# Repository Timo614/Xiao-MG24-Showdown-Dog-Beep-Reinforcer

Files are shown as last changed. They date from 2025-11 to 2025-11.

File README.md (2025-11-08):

This project demonstrates a Xiao MG24 and a custom Xiao footprint board used for sending reinforcement beeps to dog collars that operate on the 433 MHz frequency. My dogs are heavy barkers and, given their nature as rescue dogs, are jittery when it comes to people walking by outside. We ended up getting these collars off Amazon as we had issues where they would run in the backyard and excessively bark at neighbors. I opted to only store the beep element as we don't use the other features of the collars and a single beep is enough to get them to stop in most cases.

## Program Capabilities

The project in its final form has the Xiao MG24 board connected via headers to my Explorer 433 expansion board. The expansion board has a light sensor, AHT21, RFM69HCW, and two HY2.0 "Grove" inputs (one for i2c and another for uart). 

I've provided two ino files for Arduino:
- src/Explorer433-Matter.ino - a project which utilizes the Matter over Thread functionality of the Xiao MG24 to send temperature information from the AHT21 and allow triggering of dogs via Matter
- src/Explorer433.ino - a project utilizing an I2C based Grove OLED Display and a Grove button connected to the RX pin of the Xiao MG24 to demonstrate functionality in an off grid manner

The Xiao MG24 is connected to the RFM69HCW via the Xiao's pins with SPI setup, a CS and Reset pin connected, and two pins connected for DIO0 and DIO2 (which is used for the transmit mode I am using here). 

I have two demonstration videos which correspond with each of these projects. The latter video was from before the Xiao Showdown extension while the former is from after. I was able to setup a Thread Border Router on my Home Assistant over the past week and utilize the Matter functionality allowing me to take advantage of the onboard Matter over Thread capabilities.

Videos:
- https://youtu.be/2XbyZKuGWDM (with Matter)
- https://youtu.be/jQOkAnLn5Ec (original pre Matter OLED and Button demonstration)

The first demonstration video showcases the device, it being used with home assistant, and then dives into the creation process with some additional demonstrations such as the steps to record on the Flipper device for gathering the initial data.

The second demonstration video shows the AHT21 being polled and updating its status via the OLED display along with the button being used for triggering a specific collar based on a number of presses in a set window. The Xiao footprint is nice as it is small and given multiple microcontrollers from Seeed use it you can build a board and swap out the Xiao based on your needs (Thread? MG24, WIFI? ESP32C3, Bluetooth nrf52840).

## Getting Dog Collar Signals

To get the dog collar signals I used here I used my Flipper Zero device set to record on the frequency scanner and further saving them. I then took out the SD card and extracted the sub files for each collar that contained the read messages. I then utilized a script I put together to parse the sub file and export the timing as a header file I could include in my project. These header files are what were used here for the project to trigger the collars.

## Structure

- README: This file
- DogBeepFlipperSubJupyterCell.py: Jupyter cell for converting sub file to format needed
- src: Folder containing end project Arduino logic
- Hardware: Folder containing Schematic, BOM, and Gerber for the Explorer 433 board
- Enclosure: Folder containing STL files for printing the enclosure for the hardware

## Dependencies

To properly use the project several dependencies are needed on the Arduino side:
- Adafruit AHTX0
- U8g2 (only used by the second project)

Please install these libraries and their dependencies to properly compile the Arduino code.

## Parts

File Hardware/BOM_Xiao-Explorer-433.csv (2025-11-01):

ID | Name | Designator | Footprint | Quantity | Manufacturer Part | Manufacturer | Supplier | Supplier Part | Price
1 | 4.7kΩ | R2,R3 | R0805 | 2 | RMC08054.7K1%N | Tyohm(幸亚电阻) | LCSC | C269746 | 0.006
2 | 100kΩ | R1,R4 | R0805 | 2 | 0805W8D1003T5E | UNI-ROYAL(厚声) | LCSC | C407479 | 0.007
3 | 10uF | C1 | C0805 | 1 | 0805B106K160NT | FH(风华) | LCSC | C92341 | 0.027
4 | 100nF | C2,C5,C4,C3 | C0603 | 4 | TCC0603X7R104K500CT | CCTC(三环) | LCSC | C282519 | 0.002
5 | SEEEDUINO XIAO | U1 | SEEEDUINO_XIAO | 1
6 | RFM69 | U3 | RFM69HCW | 1 | RFM69HCW | SparkFun
7 | AHT21 | U6 | SENSOR-SMD_L3.0-W3.0-P1.00-BR | 1 | AHT21 | 广州奥松 | LCSC | C2827328
8 | VEML7700 | LED1 | LED-SMD_4P-L6.8-W2.4_VEML7700-TR | 1 | VEML7700-TR | VISHAY(威世) | LCSC | C504893 | 0.757
9 | CON-SMA-EDGE-S-U.FL-R-SMT | X1 | CON-SMA-EDGE-S-U.FL-R-SMT | 1
10 | i2c | GROVE2 | CONN-SMD_HY2.0-4P | 1 | HY2.0-4P-WT | CAX(创都) | LCSC | C722729 | 0.078
11 | uart | GROVE1 | CONN-SMD_HY2.0-4P | 1 | HY2.0-4P-WT | CAX(创都) | LCSC | C722729 | 0.078

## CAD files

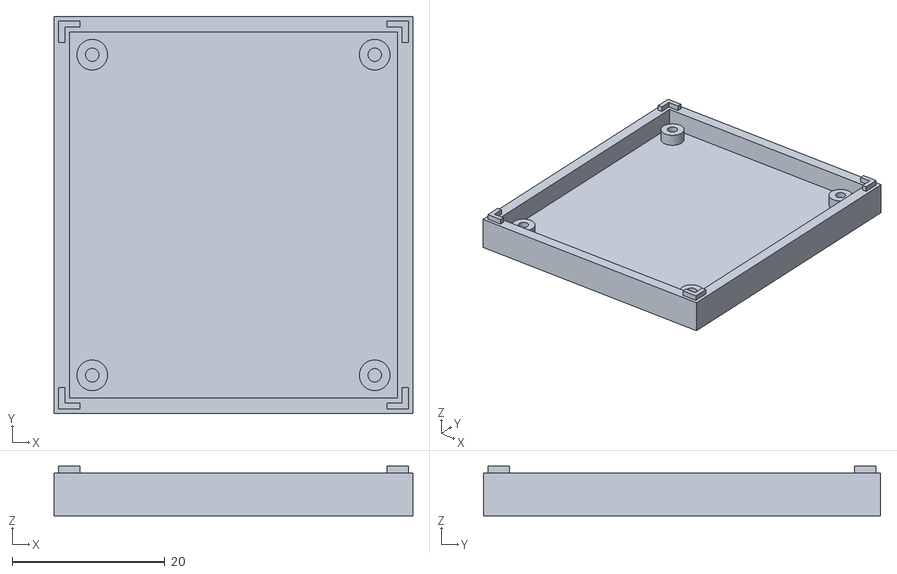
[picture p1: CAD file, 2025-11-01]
Enclosure/ExplorerBottom.stl
47.0 x 52.0 x 6.50

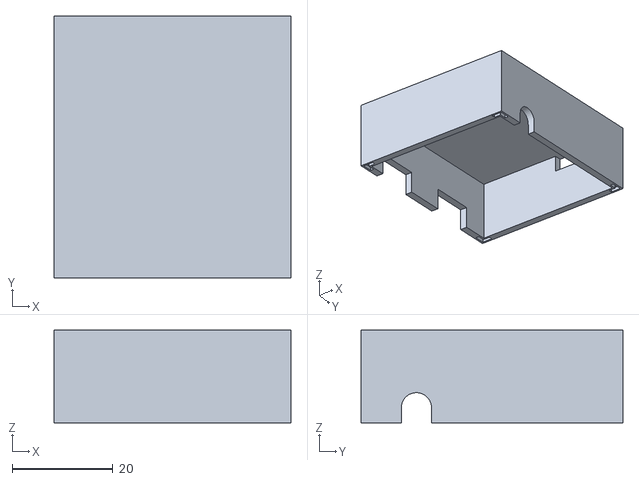
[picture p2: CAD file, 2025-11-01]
Enclosure/ExplorerTop.stl
47.0 x 52.0 x 18.4

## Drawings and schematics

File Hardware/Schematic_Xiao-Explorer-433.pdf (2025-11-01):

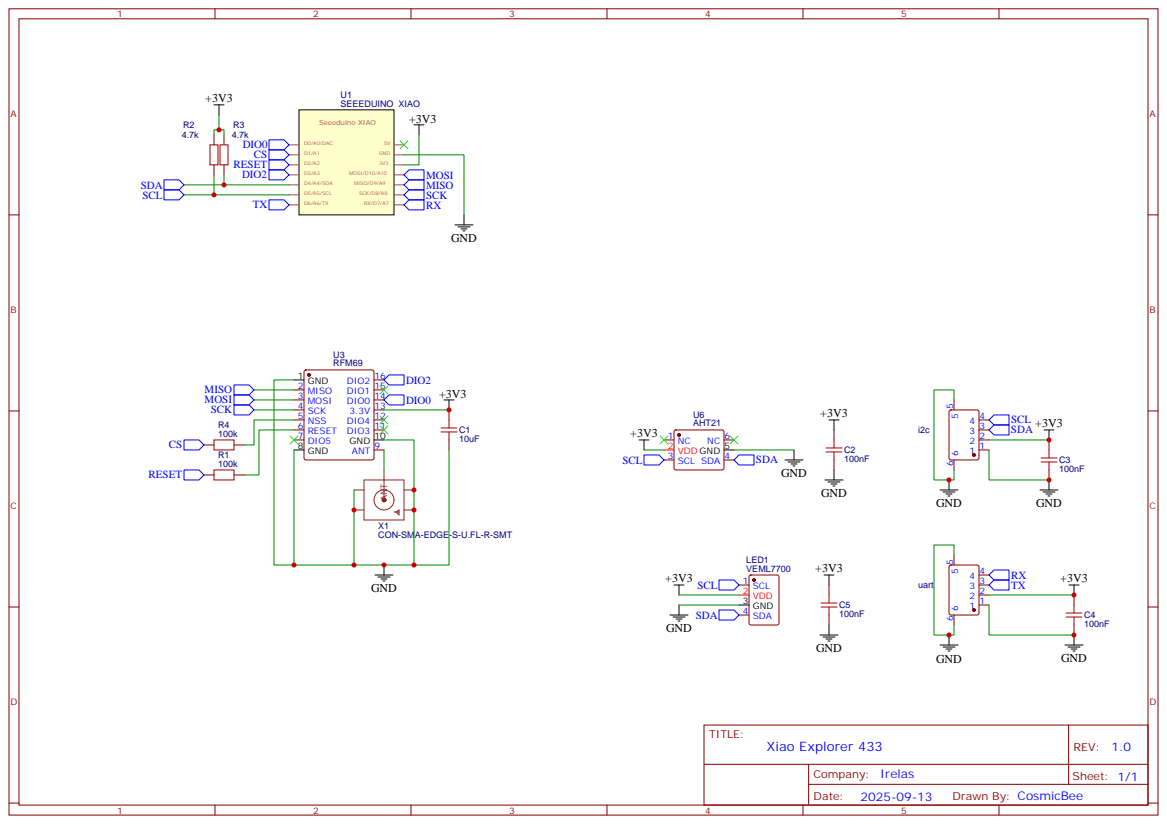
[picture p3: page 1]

CON-SMA-EDGE-S-U.FL-R-SMT

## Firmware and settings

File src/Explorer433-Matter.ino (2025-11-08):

#include <Arduino.h>
#include <SPI.h>
#include <Adafruit_AHTX0.h>
#include <Matter.h>
#include <MatterTemperature.h>
#include <MatterOnOffPluginUnit.h>
#include "mazel.h"
#include "mensch.h"
#include <stdint.h>

// ---------------- RFM69 pins (XIAO MG24) ----------------
#define PIN_RF69_INT    D0
#define PIN_RF69_CS     D1
#define PIN_RF69_RST    D2
#define PIN_RF69_DIO2   D3

// ---------------- RFM69 regs ----------------
#define REG_OPMODE        0x01
#define REG_DATAMODUL     0x02
#define REG_FRFMSB        0x07
#define REG_FRFMID        0x08
#define REG_FRFLSB        0x09
#define REG_PALEVEL       0x11
#define REG_DIOMAPPING1   0x25
#define REG_VERSION       0x10

// ~433.92 MHz
#define FRF_MSB  0x6C
#define FRF_MID  0x7A
#define FRF_LSB  0xE1

static SPISettings rfspi(4000000, MSBFIRST, SPI_MODE0);

// ---------------- Matter endpoints ----------------
MatterTemperature     matter_temp_sensor;  // read-only temp
MatterOnOffPluginUnit matter_mazel;        // controllable "switch" -> Mazel
MatterOnOffPluginUnit matter_mensch;       // controllable "switch" -> Mensch

// ---------------- AHT21 ----------------
Adafruit_AHTX0 aht;
bool aht_ok = false;
static const uint32_t AHT_PERIOD_MS = 2000;
uint32_t aht_last_ms = 0;

// ===================================================
// RFM69
// ===================================================
void rfWrite(uint8_t reg, uint8_t val) {
  SPI.beginTransaction(rfspi);
  digitalWrite(PIN_RF69_CS, LOW);
  SPI.transfer(reg | 0x80);
  SPI.transfer(val);
  digitalWrite(PIN_RF69_CS, HIGH);
  SPI.endTransaction();
}

uint8_t rfRead(uint8_t reg) {
  SPI.beginTransaction(rfspi);
  digitalWrite(PIN_RF69_CS, LOW);
  SPI.transfer(reg & 0x7F);
  uint8_t v = SPI.transfer(0x00);
  digitalWrite(PIN_RF69_CS, HIGH);
  SPI.endTransaction();
  return v;
}

void rfReset() {
  pinMode(PIN_RF69_RST, OUTPUT);
  digitalWrite(PIN_RF69_RST, HIGH);
  delay(5);
  digitalWrite(PIN_RF69_RST, LOW);
  delay(5);
  pinMode(PIN_RF69_RST, INPUT_PULLUP);
  delay(5);
}

static inline void delayAbsMicros(uint32_t us) {
  if (us >= 1000UL) { delay(us / 1000UL); us %= 1000UL; }
  if (us) delayMicroseconds((unsigned int)us);
}

static inline int32_t read_i32_p(const int32_t* base, size_t idx) {
#if defined(__AVR__)
  return (int32_t)pgm_read_dword(&base[idx]);
#else
  return base[idx];
#endif
}

void replayToDIO2(const int32_t* timings, size_t len) {
  for (size_t i = 0; i < len; ++i) {
    int32_t t = read_i32_p(timings, i);
    if (t > 0) {
      digitalWrite(PIN_RF69_DIO2, HIGH);
      delayAbsMicros((uint32_t)t);
    } else {
      digitalWrite(PIN_RF69_DIO2, LOW);
      uint32_t us = (t == INT32_MIN) ? 2147483648UL : (uint32_t)(-t);
      delayAbsMicros(us);
    }
  }
  digitalWrite(PIN_RF69_DIO2, LOW);
}

void rfConfig_OOK_DIO2() {
  rfWrite(REG_OPMODE, 0x04);  // standby
  delay(5);
  rfWrite(REG_FRFMSB, FRF_MSB);
  rfWrite(REG_FRFMID, FRF_MID);
  rfWrite(REG_FRFLSB, FRF_LSB);
  rfWrite(REG_DATAMODUL, 0x68); // OOK, continuous
  rfWrite(REG_PALEVEL, 0x5F);
  uint8_t dio = rfRead(REG_DIOMAPPING1);
  dio &= ~(0x0C);              // DIO2=data
  rfWrite(REG_DIOMAPPING1, dio);
  rfWrite(REG_OPMODE, 0x0C);   // TX
  delay(5);
}

inline void sendMazelAlert()  { replayToDIO2(Mazel,  MazelCount); }
inline void sendMenschAlert() { replayToDIO2(Mensch, MenschCount); }

// ===================================================
// setup
// ===================================================
void setup() {
  Serial.begin(115200);
  delay(200);
  Serial.println(F("Matter: AHT21 + 2x On/Off plugin units + RFM69"));

  // AHT21
  if (!aht.begin()) {
    Serial.println(F("AHT21 not found."));
    aht_ok = false;
  } else {
    aht_ok = true;
  }

  // Matter
  Matter.begin();
  matter_temp_sensor.begin();
  matter_mazel.begin();
  matter_mensch.begin();

  if (!Matter.isDeviceCommissioned()) {
    Serial.println(F("Commission this device:"));
    Serial.printf("Manual code: %s\n", Matter.getManualPairingCode().c_str());
    Serial.printf("QR URL    : %s\n", Matter.getOnboardingQRCodeUrl().c_str());
  }
  while (!Matter.isDeviceCommissioned()) { delay(200); }

  Serial.println(F("Waiting for Thread..."));
  while (!Matter.isDeviceThreadConnected()) { delay(200); }
  Serial.println(F("Thread connected."));

  Serial.println(F("Waiting endpoints..."));
  while (!matter_temp_sensor.is_online()
         || !matter_mazel.is_online()
         || !matter_mensch.is_online()) {
    delay(200);
  }
  Serial.println(F("Endpoints online."));

  // RFM69
  pinMode(PIN_RF69_CS, OUTPUT);
  digitalWrite(PIN_RF69_CS, HIGH);
  pinMode(PIN_RF69_DIO2, OUTPUT);
  digitalWrite(PIN_RF69_DIO2, LOW);
  pinMode(PIN_RF69_INT, INPUT);
  SPI.begin();
  rfReset();
  rfConfig_OOK_DIO2();

  // prime temp reading
  if (aht_ok) {
    sensors_event_t hum, temp;
    if (aht.getEvent(&hum, &temp)) {
      matter_temp_sensor.set_measured_value_celsius(temp.temperature);
    }
  }

  // show as OFF in HA initially
  matter_mazel.set_onoff(false);
  matter_mensch.set_onoff(false);

  Serial.println(F("Setup done."));
}

// ===================================================
// loop
// ===================================================
void loop() {
  const uint32_t now_ms = millis();

  // AHT21 → Matter temp
  if (now_ms - aht_last_ms >= AHT_PERIOD_MS) {
    aht_last_ms = now_ms;
    if (aht_ok) {
      sensors_event_t hum, temp;
      if (aht.getEvent(&hum, &temp)) {
        matter_temp_sensor.set_measured_value_celsius(temp.temperature);
        Serial.printf("AHT21: %.2f C, %.1f %%RH\n", temp.temperature, hum.relative_humidity);
      }
    }
  }

  // Edge-detect On/Off to act as "momentary"
  static bool last_mzl = false, last_mns = false;
  bool mzl = matter_mazel.get_onoff();
  bool mns = matter_mensch.get_onoff();

  if (mzl && !last_mzl) {           // Mazel turned ON from HA
    sendMazelAlert();
    matter_mazel.set_onoff(false);  // spring back
  }
  if (mns && !last_mns) {           // Mensch turned ON from HA
    sendMenschAlert();
    matter_mensch.set_onoff(false); // spring back
  }

  last_mzl = mzl;
  last_mns = mns;

  delay(5);
}

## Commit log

2025-11-01 Initial push
    [ExplorerBottom.stl, ExplorerTop.stl]
2025-11-01 Update to include hardware and dependencies
    [BOM_Xiao-Explorer-433.csv]
